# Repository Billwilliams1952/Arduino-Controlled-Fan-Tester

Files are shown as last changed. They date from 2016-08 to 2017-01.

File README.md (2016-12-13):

# Arduino Controlled Fan Tester

## Synopsis

Arduino based circuit for testing PC fans.  General purpose circuitry to demonstrate programming and engineering concepts. This sketch controls circuitry to test PC fans in a learning environment.

The fan under test can be powered on, speed varied using fan PWM (if present), or by PWM the fan power if no PWM input is on the fan. The fan TACH output is read and the fan RPM is automatically calculated and displayed. A separate FAN_TACH_LAMP pulse of variable pulse width is generated and is used to strobe the fan using LEDs for demonstration purposes. The user may manually control the FAN_TACH_LAMP pulse also. The current used by the fan is read and displayed.

Both the 9 VDC battery voltage and the 12VDC external voltage (if applied and selected) are monitored.

The program makes extensive use of the KY-040 Encoder library for the user interface. One encoder is used to control menu selection and modifying programmed and displayed values including:

- Fan RPM - the RPM duty cycle can be adjusted from 30% to 100%
- Fan RPM display - the RPM display can be toggled between RPM (0 to 9999) and mSec (PRI)
- Fan PWM destination - PWM can be applied to either the PWM line of the fan, or to the FET driver Q2 if the fan has no PWM line.
- Lamp sync can be toggled between FAN (if a TACH signal is present on the fan), MANually, where the user may program the lamp RPM and pulse width, or OFF.
- Lamp RPM - the user may set the Lamp RPM between 100 and 9999.
- Lamp PW - the user may program the lamp pulse width (ON time) between 0.1 and 50 msec.
- Display brightness - the user may program the LCD display between 0 (OFF) and 255 (fully ON).
- Backlight - the user may toggle the backlight ON and OFF

## Installation

Create a new folder **fantesting** in your **sketchbook** directory, then download the **fantesting.ino** file into the newly created directory. Download the ZIP file of the **ky-040** library from https://github.com/Billwilliams1952/KY-040-Encoder-Library---Arduino and extract it into the **sketchbook/libraries** folder. The schematic (PNG format) is found under the **documents** folder.

**Fan Tester Schematic**

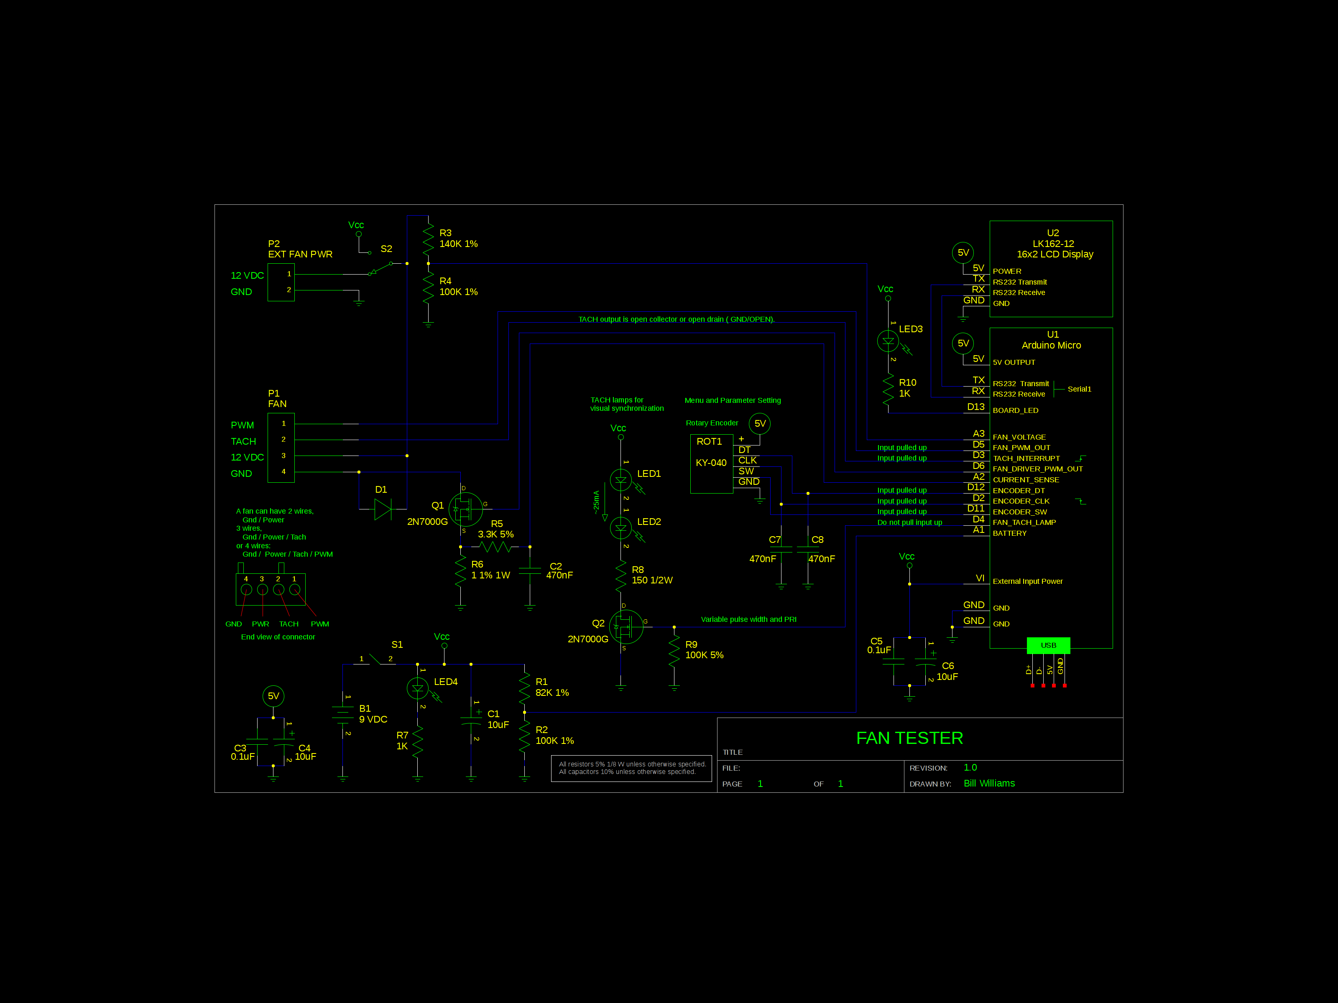
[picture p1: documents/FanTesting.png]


## API Reference

This program uses the Arduino API (**Arduino.h**, **avr/interrupt.h**, and **avr/io.h**) and the rotary encoder library **ky-040**; no other special libraries are required. It has been tested on the Arduino Micro.

## License

This program is free software: you can redistribute it and/or modify it under the terms of the GNU General Public License as published by the Free Software Foundation, either version 3 of the License, or (at your option) any later version. This program is distributed in the hope that it will be useful, but WITHOUT ANY WARRANTY; without even the implied warranty of MERCHANTABILITY or FITNESS FOR A PARTICULAR PURPOSE. See the GNU General Public License for more details. You should have received a copy of the GNU General Public License along with this program. If not, see http://www.gnu.org/licenses/.

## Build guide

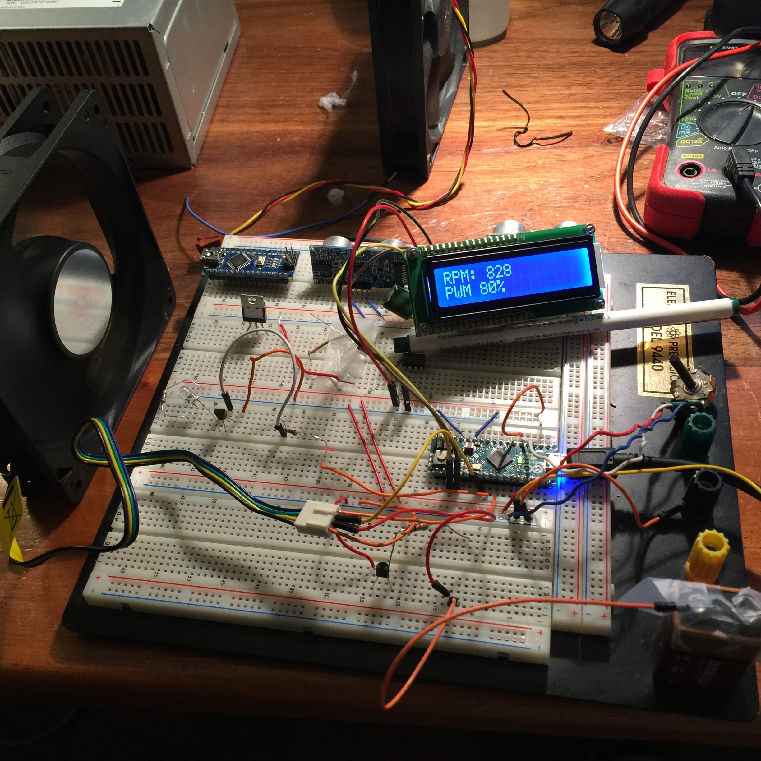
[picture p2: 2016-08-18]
documents/First breadboard setup.JPG

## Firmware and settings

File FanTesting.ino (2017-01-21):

/*
 * FanTesting.ino
 * 2016 WLWilliams
 * 
 * This sketch controls circuitry to test PC fans in a learning environment.
 * Fans can be powered on, speed varied using fan PWM (if present), or by PWM the fan
 * power if no PWM input is on the fan. The fan TACH output is read and the fan RPM is 
 * automatically calculated and displayed. A separate FAN_TACH_LAMP pulse of variable pulse width is
 * generated and is used to strobe the fan using LEDs for demonstration purposes. The user may
 * manually control the FAN_TACH_LAMP pulse also. The current used by the fan is read and displayed.
 *
 * A battery monitor checks if the battery volktage is below 7V, if so, everything halts.
 * 
 * This program is free software: you can redistribute it and/or modify it under 
 * the terms of the GNU General Public License as published by the Free Software Foundation,
 * either version 3 of the License, or (at your option) any later version. 
 * This program is distributed in the hope that it will be useful, but WITHOUT ANY WARRANTY;
 * without even the implied warranty of MERCHANTABILITY or FITNESS FOR A PARTICULAR PURPOSE.
 * See the GNU General Public License for more details. You should have received a copy of
 * the GNU General Public License along with this program.  If not, see <http://www.gnu.org/licenses/>.
 */

#include <Arduino.h>
#include <avr/interrupt.h> 
#include <avr/io.h>
#include <ky-040.h>                     // My library for using the KY-040 encoder

#if defined(__AVR_ATmega328P__) || defined(__AVR_ATmega168__)
    #include <SoftwareSerial.h>
    #define RX_PIN                  9
    #define TX_PIN                  8
    SoftwareSerial Serial1(RX_PIN, TX_PIN);      // Emulate Serial1 port 
#endif

#define FREE_MEM_TEST                 // Define to show max/min memory used under Debug
//#define CHANGE_STARTUP_SCREEN         // If defined, text is written to LCD memory to define
                                        // LCD startup text

#define BATTERY_SENSE       A1          // 9VDC divided to give 0 to 5V max
#define CURRENT_SENSE       A2          // Reference set to 2.5V giving ~ 2.44mA per bit
#define FAN_VOLTAGE         A3          // 12VDC divided to give 0 to 5 VDC

#define BOARD_LED           13          // Generic I'm Alive LED
#define ENCODER_DT          12          // Rotary DT line. Direct input
#define ENCODER_SW          11          // Rotary switch, active LOW. 470nF on pin
#define FAN_DRIVER_PWM_OUT   6          // PWM controlled by Timer0
#define FAN_PWM_OUT          5          // PWM controlled by Timer0
#define FAN_TACH_LAMP        4          // Variable PRI and Pulsewidth by Timer1
#define TACH_INPUT           3          // Fan TACH. Interrupt 0, Active HIGH
#define ENCODER_CLK          2          // Rotary switch. Interrupt 1, Active LOW. 470nF on pin

#define PULSES_FOR_1MSEC     250        // 4 usec per count assuming divide by 64 prescaler on 16 MHz clock
#define PULSES_FOR_1200RPM   12500      // 4 usec per count assuming divide by 64 prescaler on 16 MHz clock  
#define ONE_SECOND           1000000UL  // Time interval to count pulses to determine RPM
#define NO_RPM_DETECTED      -1         // Return from TACH interrupt procedure if no RPM detected
#define MIN_DUTY_CYCLE       30         // Fan min PWM
#define MAX_DUTY_CYCLE       100        // Fan max PWM
#define MIN_BRIGHTNESS       0          // LCD display
#define MAX_BRIGHTNESS       255        // LCD display

#define PULSE_LED            digitalWrite(BOARD_LED,millis() % 1000 > 500);

#define ROLLOVER             true
#define NO_ROLLOVER          false

typedef enum { MAIN_MENU, PWM_DC, BRIGHTNESS, LAMP_SOURCE, HUNDREDS, DIGITS, LAMP_PW_MSEC, GENERIC_MENU } RotaryNames;
typedef enum { FANTEST_SCREEN, LAMP_SCREEN, BATTERY_SCREEN, DISPLAY_SCREEN, DEBUG_SCREEN, ABOUT_SCREEN } MainMenuItems;
typedef enum { CURSOR_OFF, BLINKING_BLOCK, UNDERLINE } CursorType;
typedef enum { FANTEST_MENU_RETURN, FANTEST_MENU_TOGGLE_DISPLAY, FANTEST_MENU_DC, FANTEST_MENU_SETUP } FanTestMenu;
typedef enum { FANTEST_SETUP_RETURN, FANTEST_SETUP_PWM_DEST } FanTestSetupMenu;
typedef enum { LAMP_MENU_RETURN, LAMP_MENU_DC, LAMP_MENU_HUNDREDS, LAMP_MENU_DIGITS, LAMP_MENU_SETUP } LampMenu;
typedef enum { LAMP_SETUP_RETURN, LAMP_SETUP_SOURCE, LAMP_SETUP_TOGGLE_DISPLAY, LAMP_SETUP_PW } LampSetupMenu;
typedef enum { LAMP_OFF, LAMP_SYNC_TO_FAN, LAMP_SET_MANUALY } LampSource;
typedef enum { DISPLAY_MENU_RETURN, DISPLAY_MENU_BRIGHTNESS, DISPLAY_MENU_BACKLIGHT } DisplayMenu;
typedef enum { MENU_RETURN } GenericMenuItems;

/* Interrupt variables */
volatile uint8_t        tachPulseCount = 0;
volatile boolean        tachReadingReady = false;
volatile uint32_t       deltaTime;
volatile uint16_t       pulsesForLampRPM = PULSES_FOR_1200RPM, pulsesForLampPW = PULSES_FOR_1MSEC;
volatile uint8_t        clockPrescaler = 0x03;    // Four microseconds per timer tick

/* Common variables */
uint8_t dc, loopCounter;
int16_t rpm;
float   volts, current;
char    buff[7];
boolean backlight = true, displayAsRPM = true, pwmToFan = true;

#ifdef FREE_MEM_TEST
    // Debug memory
    int     minMemory = 10000, maxMemory = 0;
    
    /* Free memory calculation
     * http://www.arduino.cc/playground/Code/AvailableMemory.
     */ 

    extern unsigned int __bss_end;
    extern unsigned int __heap_start;
    extern void *__brkval;
    
    void freeMemory ( void ) {
      int free_memory;
    
      if((int)__brkval == 0)
         free_memory = ((int)&free_memory) - ((int)&__bss_end);
      else
        free_memory = ((int)&free_memory) - ((int)__brkval);
    
      if ( free_memory > maxMemory )
          maxMemory = free_memory;
      else if ( free_memory < minMemory )
          minMemory = free_memory; 
    }
    
    #define FREE_MEM  freeMemory();
#else
    #define FREE_MEM
#endif

// Use the KY-040 class to handle the state of the rotary for all of the various test cases....
ky040 rot1(ENCODER_CLK, ENCODER_DT, ENCODER_SW, 8 );

/*
 *          LCD Screen Functions
 */
void ClearScreen ( void ) {
    Serial1.write(0xFE); Serial1.write(0x58);
}

void SetCursorType ( CursorType cursorType ) {
    // There is NO blinking underline
    
    Serial1.write(0xFE);  Serial1.write(0x4B); 
    Serial1.write(0xFE);  Serial1.write(0x54);
    
    switch ( cursorType ) {
        case BLINKING_BLOCK:
            Serial1.write(0xFE);  Serial1.write(0x53);
            break;
        case UNDERLINE:
            Serial1.write(0xFE);  Serial1.write(0x4A);
            break;        
    }
}

void GoToXY ( uint8_t x, uint8_t y ) {
    Serial1.write(0xFE); Serial1.write(0x47); 
    Serial1.write(x); Serial1.write(y);
}

void GoHome ( void ) {
    Serial1.write(0xFE); Serial1.write(0x48);
}

/* ------------------------------------------------------*/

void setup() {
    FREE_MEM
  
    Serial.begin(9600);
  
    pinMode(BOARD_LED,OUTPUT);                // I'm alive pulser
    digitalWrite(BOARD_LED,HIGH);             // Initially OFF
    
    pinMode(FAN_DRIVER_PWM_OUT,OUTPUT);       // PWM to FET Q2 or FAN
    pinMode(FAN_PWM_OUT,OUTPUT);              
  
    pinMode(FAN_TACH_LAMP,OUTPUT);            // TACH Lamp not ON
    digitalWrite(FAN_TACH_LAMP,LOW);
    
    pinMode(TACH_INPUT,INPUT_PULLUP);         // TACH interrupt
    attachInterrupt(digitalPinToInterrupt(TACH_INPUT), FanTachInterrupt, RISING);  
    
    Serial1.begin(19200);                     // LCD communication
    delay(200);

    rot1.AddRotaryCounter(MAIN_MENU, FANTEST_SCREEN, FANTEST_SCREEN, ABOUT_SCREEN, 1, ROLLOVER );
    rot1.AddRotaryCounter(PWM_DC, 80, MIN_DUTY_CYCLE, MAX_DUTY_CYCLE, 5, NO_ROLLOVER );
    rot1.AddRotaryCounter(BRIGHTNESS, MAX_BRIGHTNESS, MIN_BRIGHTNESS, MAX_BRIGHTNESS, 5, NO_ROLLOVER );
    rot1.AddRotaryCounter(LAMP_SOURCE, LAMP_SYNC_TO_FAN, LAMP_OFF, LAMP_SET_MANUALY, 1, ROLLOVER );
    rot1.AddRotaryCounter(HUNDREDS, 12, 2, 99, 1, ROLLOVER );          // Setup for 1200 RPM
    rot1.AddRotaryCounter(DIGITS, 0, 0, 99, 1, ROLLOVER );             // Ditto
    rot1.AddRotaryCounter(LAMP_PW_MSEC, 20, 1, 500, 1, NO_ROLLOVER );  // Will divide by 10 - 0.1 to 50.0 msec
    rot1.AddRotaryCounter(GENERIC_MENU, 0, 0, 1, 1, ROLLOVER );        // Generic used all over

    GetFanPWMDutyCycle();                     // Start up the fan
    
#if defined ( CHANGE_STARTUP_SCREEN )
    Serial1.write(0xFE); Serial1.write(0x40);
    Serial1.print(F("  FAN TESTING     VERSION 1.0   "));   // Change version number as required
#endif

    delay(3000);
}

// Loop is not really used.  Note, RS232 over Serial is affected without some calls
// to Serial via: if (serialEventRun) serialEventRun();
void loop() { 
    FREE_MEM
      
    switch ( MainMenu() ) {
        case FANTEST_SCREEN:
            FanTestScreen();
            break;
        case LAMP_SCREEN:
            LampScreen();
            break;
        case BATTERY_SCREEN:
            SupplyScreen();
            break;
        case DISPLAY_SCREEN:
            DisplayScreen();
            break; 
        case DEBUG_SCREEN:
            DebugScreen();
            break;
        case ABOUT_SCREEN:
            AboutScreen();
            break;  
    }
}

MainMenuItems MainMenu ( void ) {
    MainMenuItems menuPos = FANTEST_SCREEN;   
    uint8_t mainMenuPosX[] = {1, 10, 1, 10, 1, 10}; 
    uint8_t mainMenuPosY[] = {1, 1, 2, 2, 1, 1};

    FREE_MEM
    
    rot1.SetRotary(MAIN_MENU);
    rot1.SetChanged();

    SetCursorType(BLINKING_BLOCK);

    while ( ! rot1.SwitchPressed() ) {
        PULSE_LED
        if ( rot1.HasRotaryValueChanged() ) {
            menuPos = (MainMenuItems)rot1.GetRotaryValue();
            GoHome();
            if ( menuPos <= DISPLAY_SCREEN ) {
                Serial1.print(F("FANTEST  LAMP   "));
                Serial1.print(F("BATTERY  DISPLAY"));
            }
            else {
                Serial1.print(F("DEBUG    ABOUT  "));
                Serial1.print(F("                "));
            }
            GoToXY(mainMenuPosX[menuPos],mainMenuPosY[menuPos]);
        }
    }
    
    return menuPos;
}

void FanTestScreen ( void ) {
    uint8_t x, y;
    FanTestMenu menuPos = FANTEST_MENU_RETURN;   
    uint8_t mainMenuPosX[] = {1, 10, 9, 16 }; 
    uint8_t mainMenuPosY[] = {1, 1, 2, 2 };

HackGoToFanTest:    // Yes yes, bad programming - sue me. Trying to keep indents under control

    FREE_MEM
    
    rot1.SetRotary(GENERIC_MENU);
    rot1.SetMaxValueOnRotary(3,GENERIC_MENU);
    rot1.SetChanged(GENERIC_MENU);

    GoHome();

    Serial1.print(F("^")); GoToXY(6,1); Serial1.print(F("V  "));
    GoToXY(6,2); Serial1.print(F("mA ")); GoToXY(12,2); Serial1.print(F("% DC^"));

    while ( true ) {
        PULSE_LED
        
        if ( rot1.HasRotaryValueChanged(GENERIC_MENU) ) {
            menuPos = (FanTestMenu)rot1.GetRotaryValue(GENERIC_MENU);
            x = mainMenuPosX[menuPos]; y = mainMenuPosY[menuPos];
            GoToXY(x,y);
        }
        
        GetFanVoltage(); dtostrf(volts,4,1,buff); 
        
        /*  All of the GotoXY()'s; Serial1.print()'s; GotoXY()'s are there to minimize 'flickering'
         *  of the block cursor. We move the cursor just long enough to print, then
         *  immediately move it back to its blinking position.
         */
        GoToXY(2,1); Serial1.print(buff); GoToXY(x,y); 

        rpm = GetRPM();
        if ( rpm == NO_RPM_DETECTED ) 
            sprintf(buff,"----");
        else if ( displayAsRPM )
            sprintf(buff,"%04d",rpm);
        else {
            float val = 60.0 / rpm * 1000.0;  // now in mSec 
            dtostrf(val,5,1,buff); 
        }
        GoToXY(9,1); Serial1.print(buff); GoToXY(x,y); 
        if ( displayAsRPM ) {
            GoToXY(13,1); Serial1.print(F(" RPM"));
        }
        else {
            GoToXY(14,1); Serial1.print(F(" ms"));
        }
        GoToXY(x,y); 

        GetCurrent(); dtostrf(current,5,1,buff); 
        GoToXY(1,2); Serial1.print(buff); GoToXY(x,y); 

        GetFanPWMDutyCycle(); sprintf(buff,"%03d",dc);  
        GoToXY(9,2); Serial1.print(buff); GoToXY(x,y); 

        if ( rot1.SwitchPressed() ) {
            switch ( menuPos ) {
                case FANTEST_MENU_RETURN:
                    rot1.SetMaxValueOnRotary(1,GENERIC_MENU);
                    return;
                case FANTEST_MENU_TOGGLE_DISPLAY:
                    displayAsRPM = ! displayAsRPM;
                    break;
                case FANTEST_MENU_DC:
                    ToggleRotaryWithGENERIC_MENU ( PWM_DC );
                    break;
                case FANTEST_MENU_SETUP:
                    FanTestSetup();
                    goto HackGoToFanTest;
            }
        }
        delay(100);
    } 
}

void FanTestSetup ( void ) {
    uint8_t x;
    FanTestSetupMenu menuPos = FANTEST_SETUP_RETURN;   
    static const char * fanPWMDest[] = {"FET Q2", "FAN   " };

    FREE_MEM

    rot1.SetRotary(GENERIC_MENU);
    rot1.SetMaxValueOnRotary(1,GENERIC_MENU);

//    "^  PWM to: FAN/FET Q2"     // FAN or FET Q2                 

    ClearScreen();
    GoHome();
    
    Serial1.print(F("^ PWM to: "));  

    while ( true ) {
        PULSE_LED
        
        if ( rot1.HasRotaryValueChanged(GENERIC_MENU) ) {
            menuPos = (FanTestSetupMenu)rot1.GetRotaryValue(GENERIC_MENU);
            x = menuPos == FANTEST_SETUP_RETURN ? 1 : 11;
            GoToXY(x,1);
        }

        GoToXY(11,1); Serial1.print(fanPWMDest[pwmToFan]); GoToXY(x,1);
          
        if ( rot1.SwitchPressed() ) {
            if ( menuPos == FANTEST_SETUP_RETURN )  return;
            pwmToFan = ! pwmToFan;
            GetFanPWMDutyCycle();     // Update PWM output pins
        }
        delay ( 100 );
    }

}

void LampScreen ( void ) {
    uint8_t x, y;
    LampMenu menuPos = LAMP_MENU_RETURN;   
    uint8_t mainMenuPosX[] = {1, 13, 8, 10, 13 }; 
    uint8_t mainMenuPosY[] = {1, 1, 2, 2, 2 };
    float period, clockPeriod, pw;
    uint16_t lastVal = rot1.GetRotaryValue(HUNDREDS) * 100 + rot1.GetRotaryValue(DIGITS);

    FREE_MEM
    
HackGoToLamp:     // Yes yes, bad programming - sue me. Trying to keep indents under control

    rot1.SetRotary(GENERIC_MENU);
    rot1.SetMaxValueOnRotary(4,GENERIC_MENU);
    rot1.SetChanged(GENERIC_MENU);
    rot1.SetChanged(HUNDREDS);
    GoHome();

    Serial1.print(F("^ Fan: "));
    GoToXY(12,1); Serial1.print(F(" "));
    GoToXY(16,1); Serial1.print(F("% "));
    GoToXY(1,2);  Serial1.print(F(" Lamp: "));
    GoToXY(12,2); Serial1.print(F(" Set "));

    while ( true ) {
        PULSE_LED

        if ( rot1.HasRotaryValueChanged(GENERIC_MENU) ) {
            menuPos = (LampMenu)rot1.GetRotaryValue(GENERIC_MENU);
            x = mainMenuPosX[menuPos]; y = mainMenuPosY[menuPos];
            GoToXY(x,y);
        }
       
        rpm = GetRPM();
        GoToXY(8,1);
        if ( rpm == NO_RPM_DETECTED )
          strcpy(buff,"----");
        else
          sprintf(buff,"%04d",rpm);
        Serial1.print(buff); GoToXY(x,y);

        switch ( (LampSource)rot1.GetRotaryValue(LAMP_SOURCE) ) {
            case LAMP_OFF:
                strcpy(buff,"    ");
                TCCR1B = 0x00;      // No interrupts
                break;
            case LAMP_SET_MANUALY:
                pw = (float)rot1.GetRotaryValue(LAMP_PW_MSEC) / 10000.0;
                if ( rot1.HasRotaryValueChanged(HUNDREDS) || rot1.HasRotaryValueChanged(DIGITS) ||
                     rot1.HasRotaryValueChanged(LAMP_SOURCE) ) {
                    lastVal = rot1.GetRotaryValue(HUNDREDS) * 100 + rot1.GetRotaryValue(DIGITS);
                    period = 60.0 / (float) lastVal;
                    noInterrupts();
                    if ( lastVal >= 1832 ) {
                        clockPeriod = 0.0000005;
                        clockPrescaler = 0x02;
                    }
                    else if ( lastVal >= 229 ) {
                        clockPeriod = 0.000004;
                        clockPrescaler = 0x03;
                    }
                    else {    // 100 RPM to 228 RPM
                        clockPeriod = 0.000016;
                        clockPrescaler = 0x04;
                    }
                    pulsesForLampRPM = (uint16_t)(period / clockPeriod);
                    pulsesForLampPW = (uint16_t)(pw / clockPeriod);
                    pulsesForLampRPM -= pulsesForLampPW;    // subtract off the pulsewidth
                    TCNT1 = 0;
                    OCR1A = pulsesForLampRPM;
                    TCCR1A = 0;
                    TCCR1B  = (1 << WGM12);       // CTC mode (compare match reset)
                    TIMSK1 |= (1 << OCIE1A);      // enable timer compare interrupt
                    TCCR1B |= clockPrescaler;     // enable counting at clockPrescaler rate 
                    interrupts();
                }
                sprintf(buff,"%04d",lastVal);
                break;
            case LAMP_SYNC_TO_FAN: 
                TCCR1B = 0x00;    // Normal operation again
                break;
        }
        
        GoToXY(8,2); Serial1.print(buff); GoToXY(x,y);
       
        GetFanPWMDutyCycle(); 
        sprintf(buff,"%03d",dc); 
        GoToXY(13,1); Serial1.print(buff); GoToXY(x,y);

        if ( rot1.SwitchPressed() ) {
            switch ( menuPos ) {
                case LAMP_MENU_RETURN:
                    rot1.SetMaxValueOnRotary(1,GENERIC_MENU);
                    return;
                case LAMP_MENU_DC:
                    ToggleRotaryWithGENERIC_MENU ( PWM_DC );
                    break;
                case LAMP_MENU_HUNDREDS:
                    if ( rot1.GetRotaryValue(LAMP_SOURCE) == LAMP_SET_MANUALY ) {
                        ToggleRotaryWithGENERIC_MENU ( HUNDREDS ); 
                        rot1.SetChanged(HUNDREDS);
                    }
                    break;   
                case LAMP_MENU_DIGITS:
                    if ( rot1.GetRotaryValue(LAMP_SOURCE) == LAMP_SET_MANUALY ) {
                        ToggleRotaryWithGENERIC_MENU ( DIGITS ); 
                        rot1.SetChanged(HUNDREDS);
                    }
                    break;                  
                case LAMP_MENU_SETUP:
                    LampSetupScreen();
                    goto HackGoToLamp; 
            }
        }
        delay(100);
    }
}

void LampSetupScreen ( void )  {
    uint8_t x, y;
    LampSetupMenu menuPos = LAMP_SETUP_RETURN;   
    uint8_t mainMenuPosX[] = {1, 7, 14, 9 }; 
    uint8_t mainMenuPosY[] = {1, 1, 1, 2 };
    float   pw;
    static const char * lampSource[] = {"OFF", "FAN", "MAN"};

    FREE_MEM
    
    rot1.SetRotary(GENERIC_MENU);
    rot1.SetMaxValueOnRotary(3,GENERIC_MENU);

//    "^Src: MAN as RPM"    // SRC FAN MAN OFF
                            // Display as RPM PRF PRI
//    "  PW: XX.X mS   "    // 0.1 to (max) 50 msec depends on current PRI                  

    GoHome();

    Serial1.print(F("^Src: "));
    GoToXY(10,1); Serial1.print(F(" as "));
    GoToXY(1,2);  Serial1.print(F("  PW: "));
    GoToXY(11,2); Serial1.print(F(" mS   "));

    while ( true ) {
        PULSE_LED

        if ( rot1.HasRotaryValueChanged(GENERIC_MENU) ) {
            menuPos = (LampSetupMenu)rot1.GetRotaryValue(GENERIC_MENU);
            x = mainMenuPosX[menuPos]; y = mainMenuPosY[menuPos];
            GoToXY(x,y);
        }
        
        GoToXY(7,1); Serial1.print(lampSource[rot1.GetRotaryValue(LAMP_SOURCE)]); GoToXY(x,y); 

        pw = (float)rot1.GetRotaryValue(LAMP_PW_MSEC) / 10.0;  
        dtostrf(pw,4,1,buff);
        GoToXY(7,2); Serial1.print(buff); GoToXY(x,y);    

        if ( rot1.SwitchPressed() ) {
            switch ( menuPos ) {
                case LAMP_SETUP_RETURN:
                    return;
                case LAMP_SETUP_SOURCE:
                    ToggleRotaryWithGENERIC_MENU ( LAMP_SOURCE ); 
                    break;
                case LAMP_SETUP_TOGGLE_DISPLAY:
                    break;
                case LAMP_SETUP_PW:
                    ToggleRotaryWithGENERIC_MENU ( LAMP_PW_MSEC ); 
                    break;
            }
        }     
        delay(100);
    }  
}

void SupplyScreen ( void ) {
    FREE_MEM
  
    rot1.SetRotary(GENERIC_MENU);
    rot1.SetMaxValueOnRotary(0,GENERIC_MENU);

    GoHome();
    Serial1.print(F("Battery: ")); GoToXY(14,1); Serial1.print(F("V  "));
    Serial1.print(F("Fan Pwr: ")); GoToXY(14,2); Serial1.print(F("V ^"));

    while ( ! rot1.SwitchPressed() ) {
        PULSE_LED
        /* 100K and 82K resistor divider. Assuming a 9VDC battery, then the 
           max voltage seen by the A/D is 4.95V, close enough to 5V. So we can just
           use the ratio of reading versus full scale of the A/D.
        */
        volts = (float)analogRead(BATTERY_SENSE) / 1023.0 * 9.0;
        dtostrf(volts,4,1,buff); 
        GoToXY(10,1); Serial1.print(buff); GoToXY(16,2);
        GetFanVoltage(); 
        dtostrf(volts,4,1,buff); 
        GoToXY(10,2); Serial1.print(buff); GoToXY(16,2);
        delay(100);
    }
}
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

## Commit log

2016-08-17 Latest edits to support Fan PWM using external driver
2016-08-18 Continuing development. TACH_SYNC works, PWM works,
2016-08-18 Added design specs and schematics
    [FanTesting.sch]
2016-09-23 Updates for Current Sense
2016-09-23 Updated schematic
    [FanTesting.sch]
2016-11-10 Major edits - updated user interface using KY-040 encoder
2016-11-10 Schematic updates to include KY-040 encoder
2016-11-10 Deleted schematic definition file
    [FanTesting.sch]
2017-01-18 Upload board layout using fritzing
    [FanTester.fzz]
2017-01-21 Automatic support for multiple Arduinbo boards
